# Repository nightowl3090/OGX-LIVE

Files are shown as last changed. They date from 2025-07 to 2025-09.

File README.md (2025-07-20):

# OGX-LIVE
OGX-Mini Boards OGX-LIVE Shell 

Fully Integrated OGX-Mini and Xbox Live Communicator
The all-in-one solution for using modern controllers on Insignia

Combining the advanced controller emulation support of WiredOpposite's OGX-Mini with Ryzee119's HAWK communicator, you can now play online with the comfort and precision of modern controllers while berating your Warthog driver for going in the wrong direction.

Configs Recommended Configurations 

Advanced Mixer Configurations 

[**Visit the web app here**](https://wiredopposite.github.io/OGX-Mini-WebApp/) to change your mappings and deadzone settings. To pair the OGX-Mini with the web app via USB, plug your controller in, then connect it to your PC, hold **Start + Left Bumper + Right Bumper** to enter web app mode. Click "Connect via USB" in the web app and select the OGX-Mini. You can also pair via Bluetooth, no extra steps are needed in that case. 

## Supported platforms
- Original Xbox
- Playstation 3
- Nintendo Switch (docked)
- XInput (use [**UsbdSecPatch**](https://github.com/InvoxiPlayGames/UsbdSecPatch) for Xbox 360, or select the patch in J-Runner while flashing your NAND)
- Playstation Classic
- DInput

## Changing platforms
By default the OGX-Mini will emulate an OG Xbox controller, you must hold a button combo for 3 seconds to change which platform you want to play on. Your chosen mode will persist after powering off the device. 

Start = Plus (Switch) = Options (Dualsense/DS4)

- XInput
    - Start + Dpad Up 
- Original Xbox
    - Start + Dpad Right
- Original Xbox Steel Battalion
    - Start + Dpad Right + Right Bumper
- Original Xbox DVD Remote
    - Start + Dpad Right + Left Bumper
- Switch
    - Start + Dpad Down
- PlayStation 3
    - Start + Dpad Left
- PlayStation Classic
    - Start + A (Cross for PlayStation and B for Switch gamepads)
- Web Application Mode
    - Start + Left Bumper + Right Bumper

After a new mode is stored, the RP2040 will reset itself so you don't need to unplug it.

## Supported devices
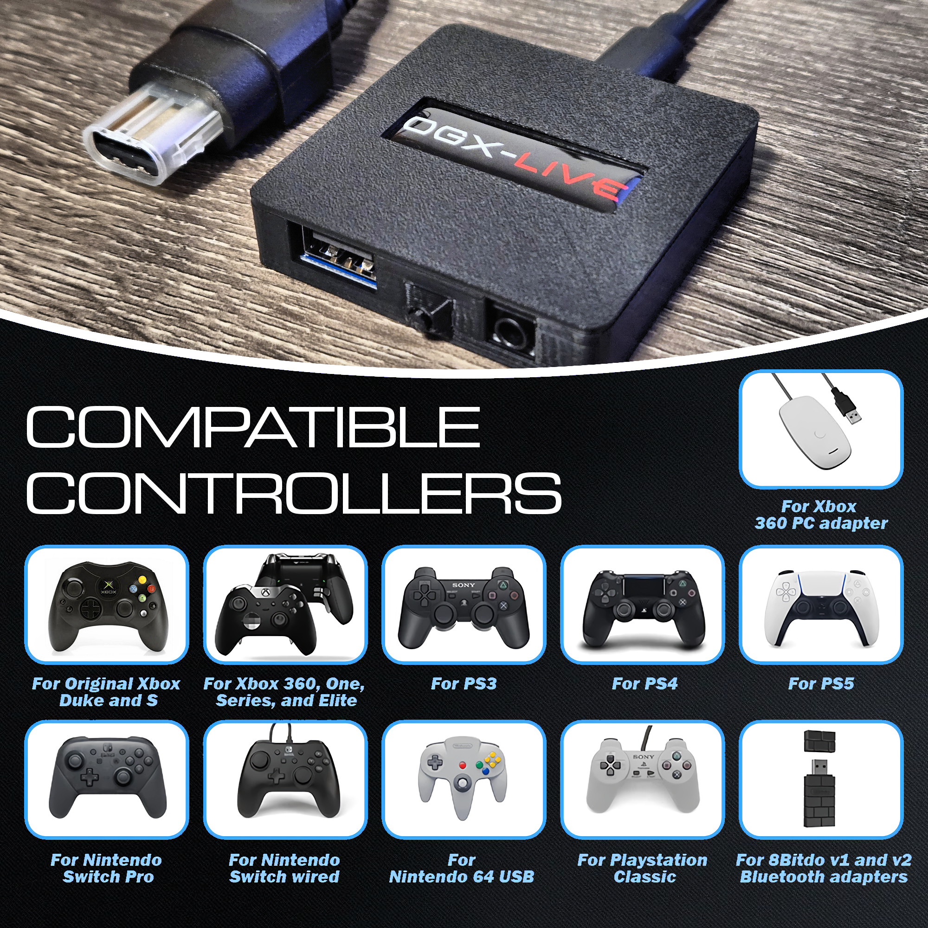
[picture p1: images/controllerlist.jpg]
Controller List
 
### Wired controllers
- Original Xbox Duke and S
- Xbox 360, One, Series, and Elite
- Dualshock 3 (PS3)
- Dualshock 4 (PS4)
- Dualsense (PS5)
- Nintendo Switch Pro
- Nintendo Switch wired
- Nintendo 64 Generic USB
- Playstation Classic
- Generic DInput
- Generic HID (mappings may need to be editted in the web app)

Note: There are some third party controllers that can change their VID/PID, these might not work correctly.

### Wireless adapters
- Xbox 360 PC adapter (Microsoft or clones)
- 8Bitdo v1 and v2 Bluetooth adapters (set to XInput mode)
- Most wireless adapters that present themselves as Switch/XInput/PlayStation controllers should work

### Wireless Bluetooth controllers (Pico W & ESP32)
**Note:** Bluetooth functionality is in early testing, some may have quirks.
- Xbox Series, One, and Elite 2
- Dualshock 3
- Dualshock 4
- Dualsense
- Switch Pro
- Steam
- Stadia
- And more

Please visit [**this page**](https://bluepad32.readthedocs.io/en/latest/supported_gamepads/) for a more comprehensive list of supported controllers and Bluetooth pairing instructions.

## Features new to v1.0.0
- Bluetooth functionality for the Pico W, Pico 2 W, and Pico+ESP32.
- Web application (connectable via USB or Bluetooth) for configuring deadzones and buttons mappings, supports up to 8 saved profiles.
- Pi Pico 2 and Pico 2 W (RP2350) support.
- Reduced latency by about 3-4 ms, graphs showing comparisons are coming.
- 4 channel functionality, connect 4 Picos and use one Xbox 360 wireless adapter to control all 4.
- Delayed USB mount until a controller is plugged in, useful for internal installation (non-Bluetooth boards only). 
- Generic HID controller support.
- Dualshock 3 emulation (minus gyros), rumble now works.
- Steel Battalion controller emulation with a wireless Xbox 360 chatpad.
- Xbox DVD dongle emulation. You must provide or dump your own dongle firmware, see the Tools directory.
- Analog button support on OG Xbox and PS3.
- RGB LED support for RP2040-Zero and Adafruit Feather boards.

## Planned additions
- More accurate report parser for unknown HID controllers
- Hardware design for internal OG Xbox install
- Hardware design for 4 channel RP2040-Zero adapter
- Wired Xbox 360 chatpad support
- Wired Xbox One chatpad support
- Switch (as input) rumble support
- Generic bluetooth dongle support
- Button macros
- Rumble settings (intensity, enabled/disable, etc.)

## Communicator Use

Recommended configuration: 12 foot 3.5mm TTRS cable and 12 foot USB-A cable
Alternatively you could use a USB-C extension and then shorter cable runs for the headset and controller.
8-BitDo or equivalent wireless adapter is necessary for wireless function. 

The OGX-LIVE provides feature parity with the original communicator with the following differences:
- Dual independent processors for gamepad and audio processing to eliminate latency
- Support for a wide array of modern controllers and input devices. Full list available on the OGX-LIVE Github repository
- A 3.5mm TRRS jack is used to support more generic headsets. (Stereo headsets will output as mono.)
- The volume wheel is replaced with a button. Volume is indicated by LED brightness.
- The Xbox chat feature only outputs voice audio, so a single ear chat headset is recommended.

Tip: When searching online for compatible headsets use the term: "mono chat headset 3.5" to get the best results for single ear chat headsets

Usage:
**Press the button to increment the volume. Once maximum volume is reached, it will cycle back to zero.
**Hold the button for 1 second to mute and disable the microphone input (LED will flash at 1Hz).
**Hold the button 2 seconds to enter microphone gain adjustment mode (LED will flash at 4Hz).
**Volume and microphone gain adjustments will be saved internally. You can reset these to default by holding the button down for 8 seconds.

FAQ:
Why can't I hear the in-game audio? 
- The original Xbox's headset was designed to playback chat audio only, however, with the use of an external mixer you could mix the audio output from the Xbox with the chat audio from the Hawk for a full headphone gaming experience. 
What is the pinout of the headphone jack?
- OGX-LIVE's headphone jack is wired as per CTIA standard TRRS. There is another less common standard called OMTP. This will not work but adapters are available.
Microphone is really quiet?
- You can increase the microphone gain above default. Hold the Hawk button down for more than 2 seconds to enter gain adjustment mode. The LED will blink 4 times per second to show it is in the right mode then press the button to increase the gain. Hold for 1 second to exit. If this is still too quiet, you can modify the MAX_MICROPHONE_GAIN variable and recompile the code to bump it up even higher.
Speaker is really quiet?
- Adjust the volume by pressing the button until the LED is at its maximum brightness. Unfortunately, it is already compiled to the maximum allowable by OGX-LIVE. If it is still too quiet, your headset's impedance may be too low.

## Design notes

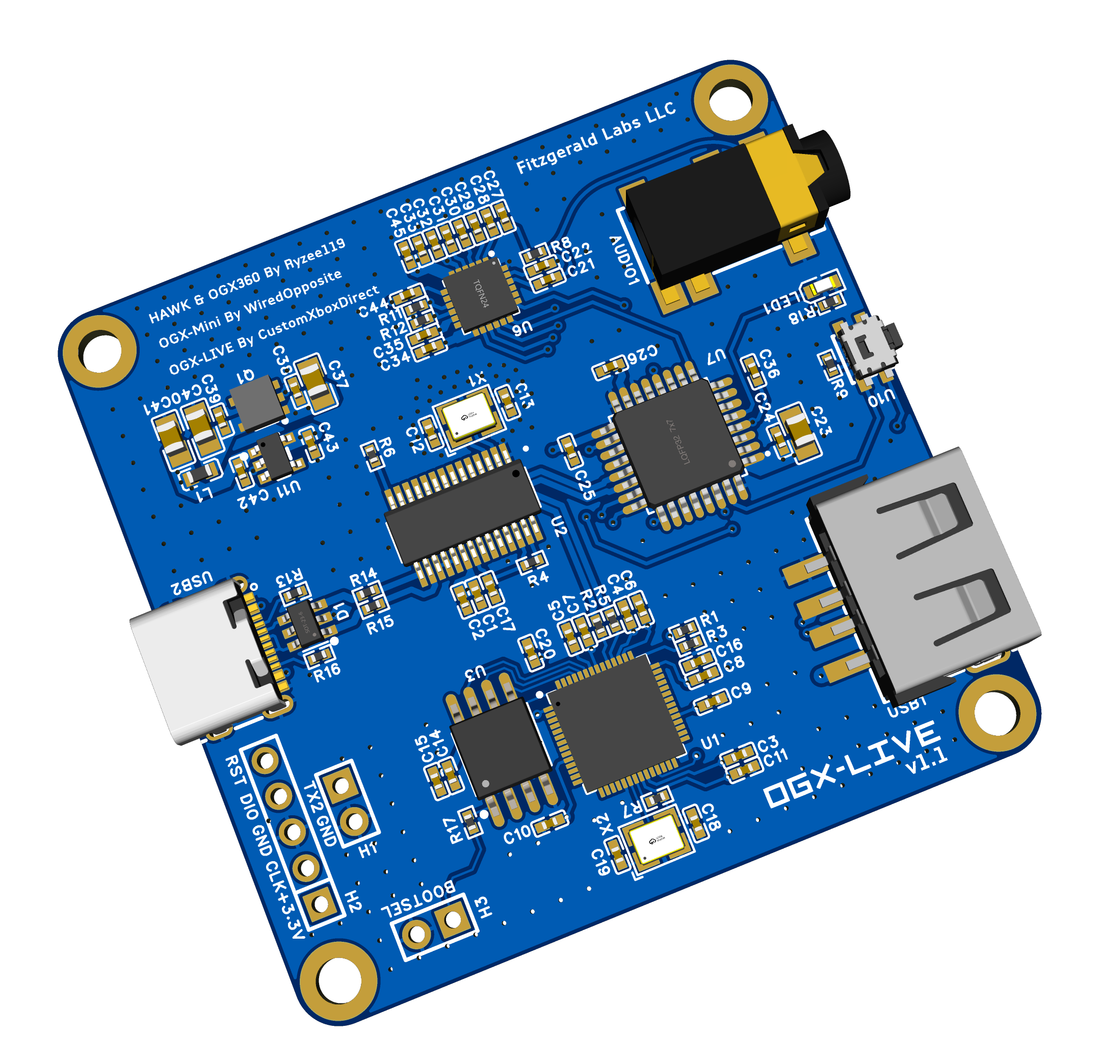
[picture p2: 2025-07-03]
images/3D_PCB1_2025-07-02.png

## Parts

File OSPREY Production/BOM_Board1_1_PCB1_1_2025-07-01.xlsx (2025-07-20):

No. | Quantity | Comment | Designator | Footprint | Value | Manufacturer Part | Manufacturer | Supplier Part | Supplier
1 | 1 | PJ-3420-A-SMT | AUDIO1 | AUDIO-SMD_PJ-3420-A-SMT_C319102 |  | PJ-3420-A-SMT | XKB Connectivity(中国星坤) | C319102 | LCSC
2 | 10 | 100nF | C1,C24,C25,C26,C33,C36,C38,C39,C42,C43 | C0402 | 100nF | CL05B104KO5NNNC | SAMSUNG(三星) | C1525 | LCSC
3 | 2 | 10uF | C2,C17 | C0402 | 10uF | CL05A106MQ5NUNC | SAMSUNG(三星) | C15525 | LCSC
4 | 2 | 15pF | C12,C13 | C0402 | 15pF | 0402CG150F500NT | FH(风华) | C285151 | LCSC
5 | 10 | 1uF | C21,C22,C27,C28,C29,C30,C31,C32,C34,C35 | C0402 |  | CC0402KRX5R5BB105 | YAGEO(国巨) | C106253 | LCSC
6 | 4 | 10uF | C23,C37,C40,C41 | C0805 |  | 0805X106M250NT | FH(风华) | C669099 | LCSC
7 | 2 | 10uF | C44,C45 | C0402 | 10uF | HGC0402R5106M100NTEJ | Chinocera(华瓷) | C7472949 | LCSC
8 | 1 | USBLC6-2SC6 | D1 | SOT-23-6_L2.9-W1.6-P0.95-LS2.8-BL |  | USBLC6-2SC6 | TECH PUBLIC(台舟) | C2827654 | LCSC
9 | 1 | MPZ1608S101ATAH0 | L1 | L0603 |  | MPZ1608S101ATAH0 | TDK | C107332 | LCSC
10 | 1 | XL-1608UGC-04 | LED1 | LED0603-RD_GREEN |  | XL-1608UGC-04 | XINGLIGHT(成兴光) | C965804 | LCSC
11 | 1 | XC6220B331MR-G | Q1 | SOT-25_L3.0-W1.6-P0.95-LS2.8-TL |  | XC6220B331MR-G | TOREX(特瑞仕) | C86534 | LCSC
12 | 1 | 2.7kΩ | R6 | R0402 | 2.7kΩ | 0402WGF2701TCE | UNI-ROYAL(厚声) | C25885 | LCSC
13 | 4 | 1.5kΩ | R8,R9,R11,R12 | R0402 | 1.5kΩ | RC0402FR-071K5L | YAGEO(国巨) | C114759 | LCSC
14 | 2 | 5.1kΩ | R13,R16 | R0402 | 5.1kΩ | 0402WGF5101TCE | UNI-ROYAL(厚声) | C25905 | LCSC
15 | 2 | 0Ω | R14,R15 | R0402 | 0Ω | 0402WGF0000TCE | UNI-ROYAL(厚声) | C17168 | LCSC
16 | 1 | 150Ω | R18 | R0402 | 150Ω | RC0402FR-07150RL | YAGEO(国巨) | C138054 | LCSC
17 | 1 | FE1.1S-BSOP28BCN | U2 | SSOP-28_L9.9-W3.9-P0.64-LS6.0-BL-1 |  | FE1.1S-BSOP28BCN | TERMINUS | C9359 | LCSC
18 | 1 | MAX9860ETG+T | U6 | TQFN-24_L4.0-W4.0-P0.50-BL-EP |  | MAX9860ETG+T | ADI(亚德诺)/MAXIM(美信) | C516787 | LCSC
19 | 1 | STM32G431K6T6 | U7 | LQFP-32_L7.0-W7.0-P0.80-LS9.0-BL |  | STM32G431K6T6 | ST(意法半导体) | C730097 | LCSC
20 | 1 | TSC4A 160gf-WZ 016 | U10 | KEY-SMD_TSC4A |  | TSC4A 160gf-WZ 016 | SHOU HAN(首韩) | C2906284 | LCSC
21 | 1 | XC6220B181MR | U11 | SOT-23-5_L2.9-W1.6-P0.95-LS2.8-BR |  | XC6220B181MR | TDSEMIC(拓电半导体) | C22466447 | LCSC
22 | 1 | 10.0 QHHTZB6.3 | USB1 | USB-A-TH_10.0QHHTZB6.3 |  | 10.0 QHHTZB6.3 | SHOU HAN(首韩) | C668591 | LCSC
23 | 1 | USB-310-B-SU | USB2 | USB-C-SMD_20P-P0.50-L7.4-W8.9 |  | USB-310-B-SU | HOOYA(皓宇电子) | C309347 | LCSC
24 | 1 | 12MHz | X1 | OSC-SMD_4P-L3.2-W2.5-BL | 12MHz | X322512MSB4SI | YXC(扬兴晶振) | C9002 | LCSC

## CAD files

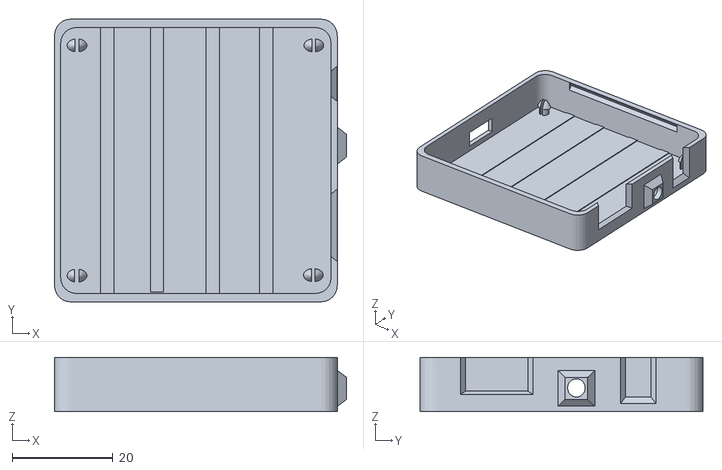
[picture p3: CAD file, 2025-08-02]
OGX-LIVE 3D Print Shell Files/OGX-LIVE Shell Bottom.stl
57.8 x 56.0 x 10.7

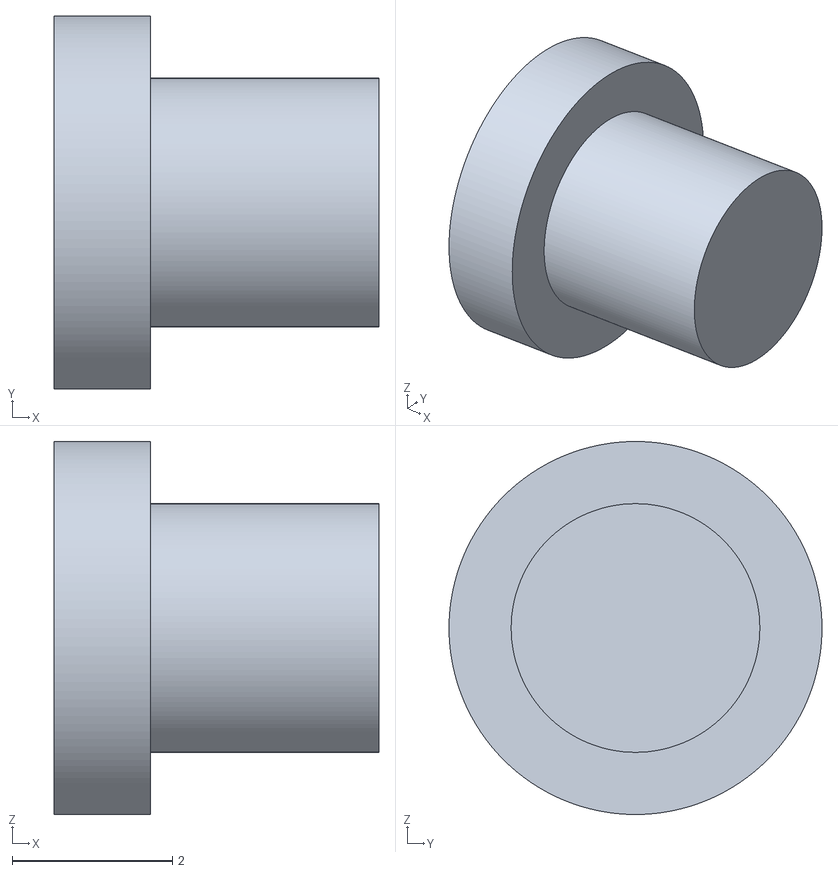
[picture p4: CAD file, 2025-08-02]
OGX-LIVE 3D Print Shell Files/OGX-LIVE Shell Button.stl
4.05 x 4.65 x 4.65

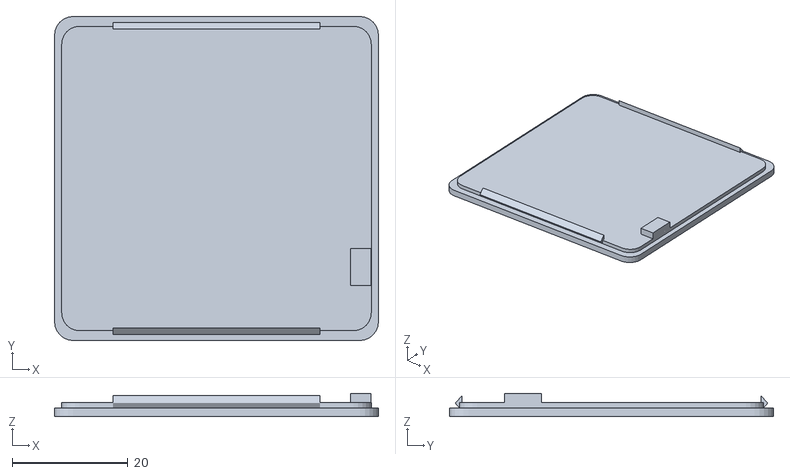
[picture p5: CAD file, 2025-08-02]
OGX-LIVE 3D Print Shell Files/OGX-LIVE Shell Top.stl
56.0 x 56.0 x 3.98

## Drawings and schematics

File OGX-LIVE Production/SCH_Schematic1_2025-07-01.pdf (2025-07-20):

## Raspberry Pi

# QSPI_SD3 51 DVDD ⁵⁰

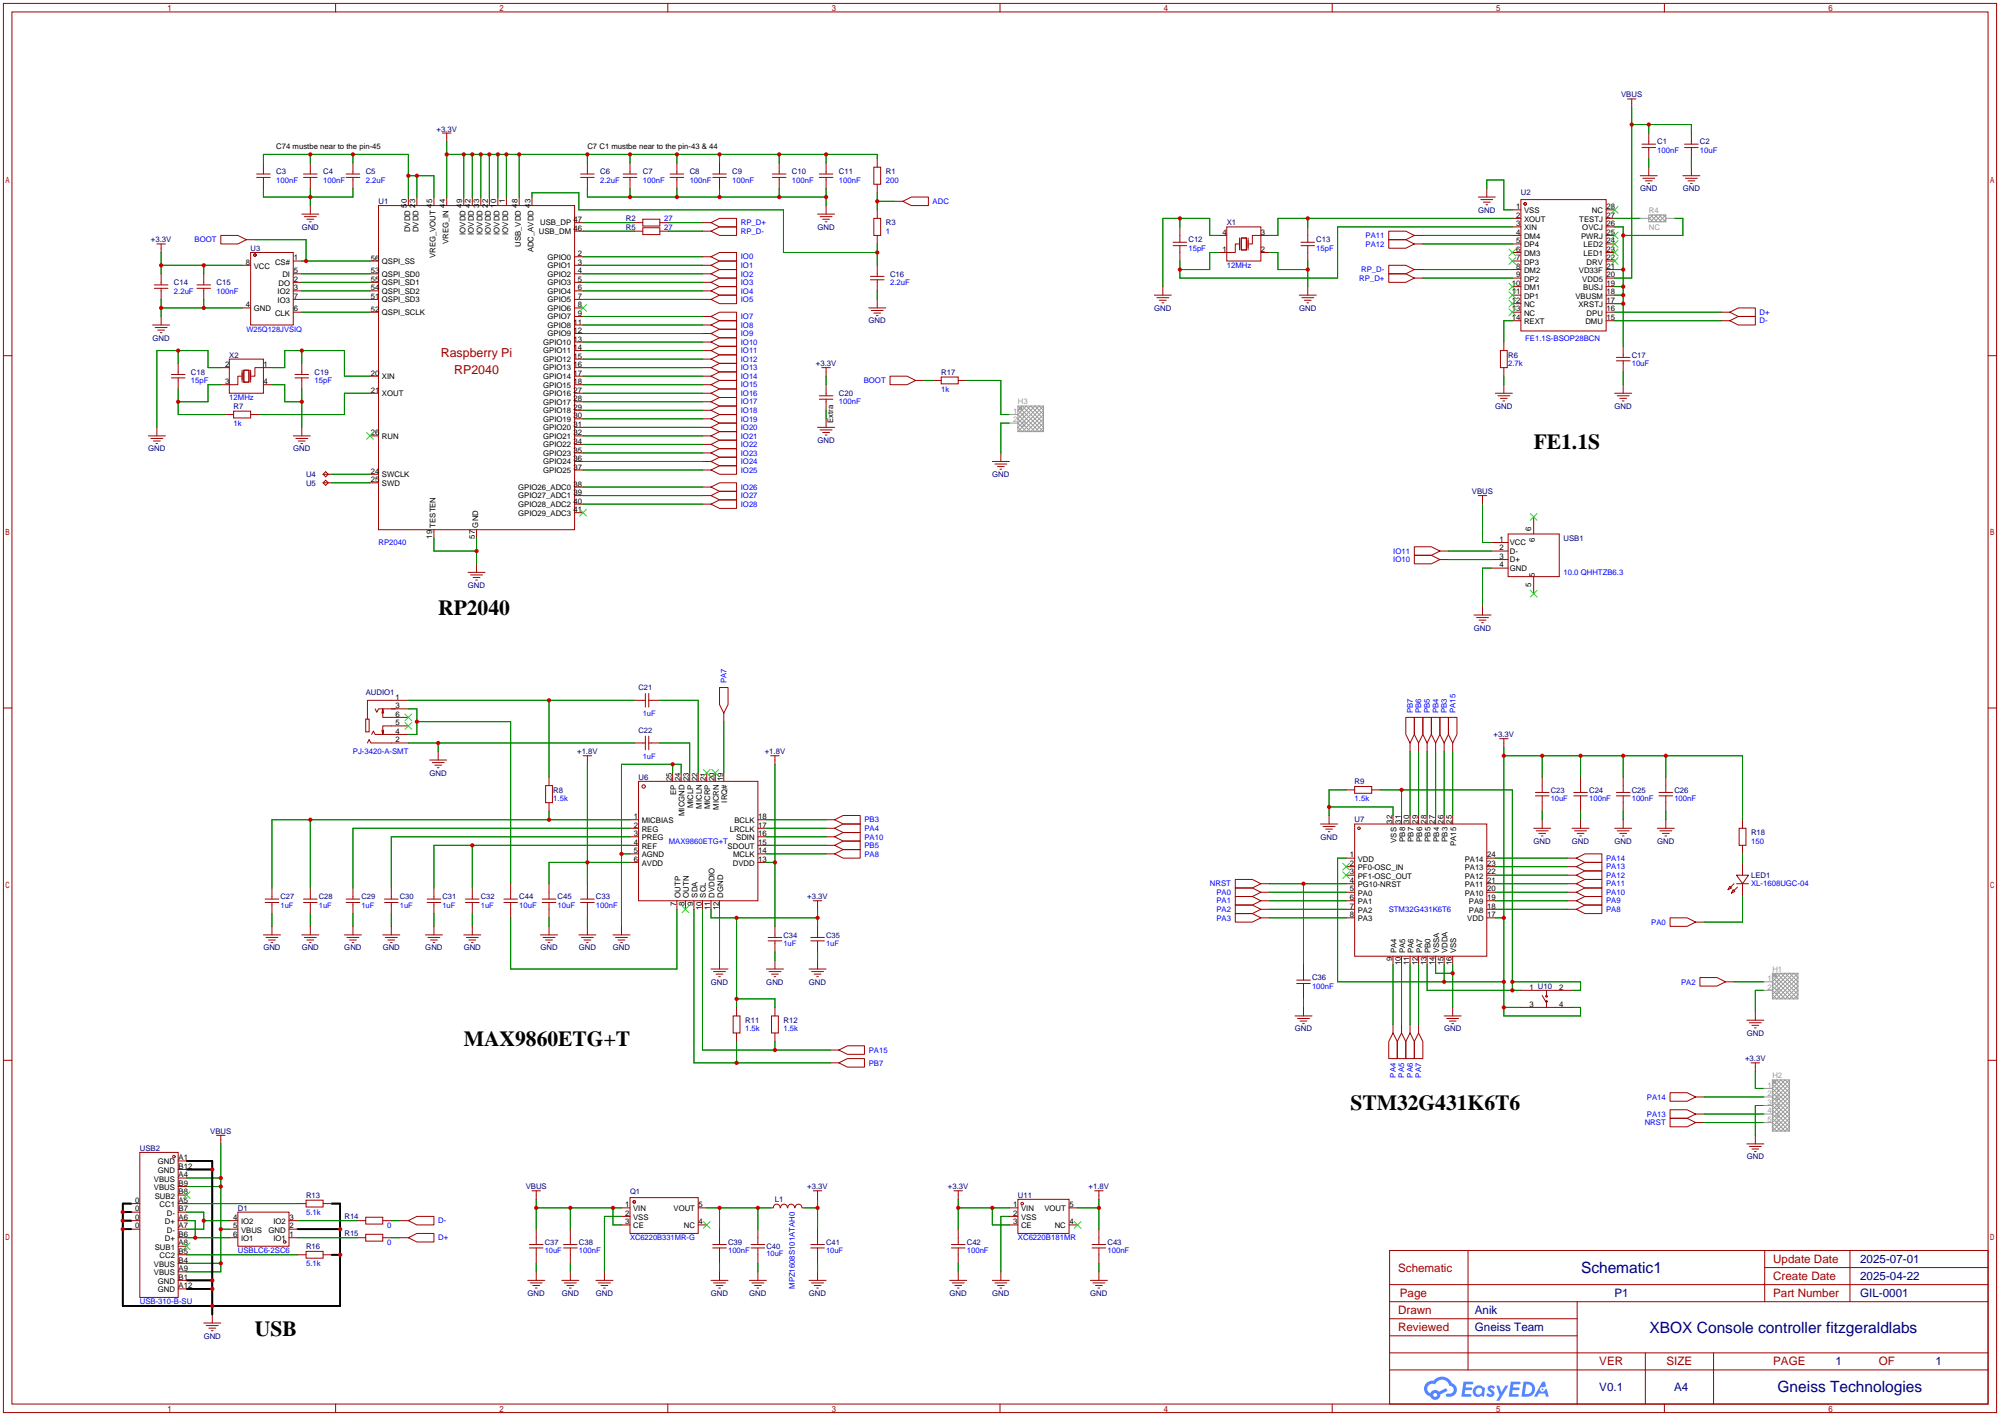
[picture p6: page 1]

IRQ# 19 MICRN 20 MICRP 21 MICLN 22 MICLP 23 MICGND 24 EP

DVDD 13 MCLK 14 SDOUT 15 SDIN 16 LRCLK 17 BCLK 18

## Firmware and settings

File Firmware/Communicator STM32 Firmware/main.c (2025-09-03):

// SPDX-License-Identifier: MIT
// SPDX-FileCopyrightText: 2024 Ryan Wendland

// i2S Audio codec to USB bridge.
// USB is coded to simulate an Xbox Live Communicator for the Original Xbox
// I2S is generated with STMs SAI interface as a slave device. The audio codex is a MAX9860 and is the master device.
// The STM provides a master clock to the MAX9860 using MCO and the MAX9860 provides the bit clock and frame sync back
// to the STM. The master clock is provided to the MAX9860 by STM's HSI48 which is automatically adjusted to match the
// USB clock using the clock recovery system. This eliminates the need for a crystal or other clock source and prevents
// drift between the USB clock and onboard clocks. All the I2s audio processing is circular DMA/interrupt driven and is
// pushed into a FIFO buffer for microphone data, and read from a FIFO buffer for speaker data. The USB interface reads
// from the FIFO for microphone data and writes to the FIFO for speaker data. This is all interrupt driven.

#include "main.h"
#include "eeprom_emulation/ee.h"
#include "max9860/max9860.h"
#include "usbd/usb_device.h"
#include "fifo.h"

#define RAM_FUNC __attribute__((section(".RamFunc")))
#define MCO_FREQ 12000000UL  // 48Mhz / 4 See SystemClock_Config

void SystemClock_Config(void);
static void MX_GPIO_Init(void);
static void MX_DMA_Init(void);
static void MX_I2C1_Init(void);
static void MX_SAI1_Init(void);
static void MX_USART2_UART_Init(void);
static void MX_TIM2_Init(void);
static void set_led_brightness(uint8_t percent);
static void start_new_audio_stream(uint32_t sample_rate);

// Peripheral handles
I2C_HandleTypeDef hi2c1;
SAI_HandleTypeDef hsai_BlockA1; // Speaker
SAI_HandleTypeDef hsai_BlockB1; // Microphone
DMA_HandleTypeDef hdma_sai1_a;
DMA_HandleTypeDef hdma_sai1_b;
TIM_HandleTypeDef htim2;
UART_HandleTypeDef huart2;

// Codec
static max9860_device_t max9860;
static uint32_t pending_sample_rate_change = 0;
static uint8_t pending_agc_change = 0;
static uint8_t microphone_muted = 0;

// Non volatile storage
#define HAWK_MAGIC (0x4841574B)
typedef struct {
    uint32_t magic;
    int8_t volume;
    uint8_t mic_gain;
    uint8_t reserved[2];
} hawk_storage_t;
hawk_storage_t ee;
uint32_t ee_dirty = 0;

// Data fifos for linking USB and SAI I2S
#define FIFO_BUFF_SZ (48 * 8)
static fifo_t fifo_speaker;
static fifo_t fifo_mic;
static uint8_t fifo_speaker_buffer[FIFO_BUFF_SZ];
static uint8_t fifo_mic_buffer[FIFO_BUFF_SZ];

// UART FIFO
static uint8_t uart_fifo[256];
static uint32_t uart_fifo_head = 0, uart_fifo_tail = 0;
void io_puts(const char *s, void *ctx) {
    while (*s) {
        uart_fifo[uart_fifo_tail] = *s++;
        uart_fifo_tail = (uart_fifo_tail + 1) % sizeof(uart_fifo);
    }
}

// Circular DMA buffers for SAI TX and RX
#define SAI_DMA_BUFFER_BYTES (FIFO_BUFF_SZ)
static uint8_t tx_dma_buffer[SAI_DMA_BUFFER_BYTES] __attribute__((aligned(4)));
static uint8_t rx_dma_buffer[SAI_DMA_BUFFER_BYTES] __attribute__((aligned(4)));

// LED
static uint32_t led_rate = 0;
static uint8_t led_brightness = 0;

void (*SysMemBootJump)(void);

int main(void) {
    HAL_Init();
    SystemClock_Config();

    // Initialize all configured peripherals
    MX_GPIO_Init();
    MX_DMA_Init();
    MX_USART2_UART_Init();
    MX_I2C1_Init();
    MX_SAI1_Init();
    MX_TIM2_Init();
    MX_USB_Device_Init();

    io_puts("HAWK!\n", NULL);

    // Emulated EEPROM
    EE_Init(&ee, sizeof(ee));
    EE_Read();
    if (ee.magic != HAWK_MAGIC) {
        io_puts("EEPROM RESET\n", NULL);
        memset(&ee, 0, sizeof(ee));
        ee.magic = HAWK_MAGIC;
        ee.volume = DEFAULT_SPEAKER_GAIN;
        ee.mic_gain = DEFAULT_MICROPHONE_GAIN;
        EE_Write(true);
    }

    if (max9860_init(&max9860, &hi2c1, MCO_FREQ) == false) {
        io_puts("MAX9860 INIT FAILED\n", NULL);
        while (1) {
            set_led_brightness(100);
            HAL_Delay(100);
            set_led_brightness(0);
            HAL_Delay(100);
        }
    }

    // Setup audio codec
    max9860_set_volume(&max9860, 20);
    max9860_mic_agc_enable(&max9860);
    max9860_start(&max9860);
    led_brightness = (((ee.volume - MIN_SPEAKER_GAIN) * 100) / (MAX_SPEAKER_GAIN - MIN_SPEAKER_GAIN));
    led_rate = 0;

    // Prepare FIFOs
    fifo_init(&fifo_speaker, fifo_speaker_buffer, sizeof(fifo_speaker_buffer));
    fifo_init(&fifo_mic, fifo_mic_buffer, sizeof(fifo_mic_buffer));

    // Start the I2s Interface DMA circular buffer.
    start_new_audio_stream(DEFAULT_SAMPLE_RATE);

    while (1) {
        uint32_t current_tick = HAL_GetTick();

        // Process and clear max9860 IRQs
        if (max9860.has_irq) {
            max9860.has_irq = false;
            // Read and clear the status
            if (max9860_get_irq_status(&max9860)) {
                io_puts("IRQ: ", NULL);
                io_puts((max9860.INTRSTATUS & MAX9860_CLD) ? "CLD " : "", NULL);
                io_puts((max9860.INTRSTATUS & MAX9860_SLD) ? "SLD " : "", NULL);
                io_puts((max9860.INTRSTATUS & MAX9860_ULK) ? "ULK " : "", NULL);
                io_puts("\n", NULL);
            }
        }

        // Handle a sample rate change
        if (pending_sample_rate_change) {
            io_puts("SR: ", NULL);
            io_puts((pending_sample_rate_change == 8000)    ? "8k"
                    : (pending_sample_rate_change == 11025) ? "11k"
                    : (pending_sample_rate_change == 16000) ? "16k"
                    : (pending_sample_rate_change == 22050) ? "22k"
                    : (pending_sample_rate_change == 24000) ? "24k"
                                                            : "???",
                    NULL);
            io_puts("\n", NULL);
            start_new_audio_stream(pending_sample_rate_change);
            pending_sample_rate_change = 0;
        }

        // Handle auto gain control toggle
        if (pending_agc_change & 0x80) {
            uint8_t agc = pending_agc_change & 0x7F;
            pending_agc_change = 0;
            io_puts("AGC: ", NULL);
            io_puts(agc ? "ON\n" : "OFF\n", NULL);
            if (agc) {
                max9860_mic_agc_enable(&max9860);
            } else {
                max9860_mic_agc_disable(&max9860, DEFAULT_MICROPHONE_GAIN);
                max9860_set_mic_gain(&max9860, ee.mic_gain);
            }
            pending_agc_change = 0;
        }

        // Flush UART fifo
        if (uart_fifo_head != uart_fifo_tail) {
            uint32_t len = (uart_fifo_head < uart_fifo_tail) ? (uart_fifo_tail - uart_fifo_head)
                                                             : (sizeof(uart_fifo) - uart_fifo_head);
            HAL_UART_Transmit(&huart2, &uart_fifo[uart_fifo_head], len, 0xFFFF);
            uart_fifo_head = (uart_fifo_head + len) % sizeof(uart_fifo);
        }

        // Prevent thrashing emulated eeprom. Only write if dirty and some period has passed
        if (ee_dirty && (HAL_GetTick() - ee_dirty) > 10000) {
            EE_Write(true);
            ee_dirty = 0;
            io_puts("EEPROM WRITTEN\n", NULL);
        }

        // Handle flashing of the LED
        static uint32_t led_tick = 0;
        static uint32_t tgl = 0;
        uint32_t led_held = current_tick - led_tick;
        if (led_rate) {
            if (led_held > led_rate) {
                led_tick = current_tick;
                set_led_brightness((tgl ^= 1) ? led_brightness : 0);
            }
        } else {
            set_led_brightness(led_brightness);
        }

        // The button has 4 modes. Normal, Mute, Mic Gain, and EEPROM Reset
        // Normal mode adjusts the volume. The LED brightness is set to the volume level.
        // Mute does not transfer any microphone information. This is indicated a slow flash of the LED.
        // Mic Gain mode makes the button adjust the microphone gain. This is indicated by a medium flash of the LED.
        // EEPROM Reset mode resets the EEPROM to defaults this is indicated by a fast flash of the LED.
        typedef enum { NORMAL_MODE, MUTE_MODE, MIC_GAIN_MODE, EEPROM_RESET_MODE } button_mode_t;
        static button_mode_t button_mode = NORMAL_MODE;
        static uint8_t last_button_state = 0;
        static uint32_t button_pressed_tick = 0;

        uint8_t button_state = HAL_GPIO_ReadPin(BUTTON_GPIO_Port, BUTTON_Pin);
        if (button_state && button_state != last_button_state) {
            button_pressed_tick = current_tick;
        }

        if (!button_state && button_state != last_button_state) {
            if (current_tick - button_pressed_tick > 8000) {
                io_puts("EEPROM RESET\n", NULL);
                button_mode = EEPROM_RESET_MODE;
                led_rate = 100;
                led_brightness = 100;
                memset(&ee, 0, sizeof(ee));
                ee.magic = HAWK_MAGIC;
                ee.volume = DEFAULT_SPEAKER_GAIN;
                ee.mic_gain = DEFAULT_MICROPHONE_GAIN;
                EE_Write(true);

            } else if (current_tick - button_pressed_tick > 2000) {
                io_puts("MIC GAIN\n", NULL);
                button_mode = (button_mode == MIC_GAIN_MODE) ? NORMAL_MODE : MIC_GAIN_MODE;
                microphone_muted = 0;
                led_rate = 250;
                led_brightness =
                    (((ee.mic_gain - MIN_MICROPHONE_GAIN) * 100) / (MAX_MICROPHONE_GAIN - MIN_MICROPHONE_GAIN));

            } else if (current_tick - button_pressed_tick > 500) {
                if (button_mode != MIC_GAIN_MODE) {
                    io_puts("MUTE\n", NULL);
                    button_mode = MUTE_MODE;
                    led_rate = 1000;
                    led_brightness = 50;
                    microphone_muted = 1;
                } else {
                    button_mode = NORMAL_MODE;
                    led_rate = 0;
                    led_brightness = (((ee.volume - MIN_SPEAKER_GAIN) * 100) / (MAX_SPEAKER_GAIN - MIN_SPEAKER_GAIN));
                }

            } else if (current_tick - button_pressed_tick > 50) {
                if (button_mode == NORMAL_MODE) {
                    ee.volume += SPEAKER_INCREMEMENT;
                    // When it reaches max, one more press is no change, 2nd press resets to zero
                    if (ee.volume > (MAX_SPEAKER_GAIN + SPEAKER_INCREMEMENT)) {
                        ee.volume = MIN_SPEAKER_GAIN;
                    }
                    max9860_set_volume(&max9860, ee.volume);
                    led_brightness = (((ee.volume - MIN_SPEAKER_GAIN) * 100) / (MAX_SPEAKER_GAIN - MIN_SPEAKER_GAIN));
                    ee_dirty = HAL_GetTick();

                } else if (button_mode == MIC_GAIN_MODE) {
                    ee.mic_gain += MICROPHONE_INCREMEMENT;
                    // When it reaches max, one more press is no change, 2nd press resets to zero
                    if (ee.mic_gain > (MAX_MICROPHONE_GAIN + MICROPHONE_INCREMEMENT)) {
                        ee.mic_gain = MIN_MICROPHONE_GAIN;
                    }
                    max9860_set_mic_gain(&max9860, ee.mic_gain);
                    led_brightness =
                        (((ee.mic_gain - MIN_MICROPHONE_GAIN) * 100) / (MAX_MICROPHONE_GAIN - MIN_MICROPHONE_GAIN));
                    ee_dirty = HAL_GetTick();

                } else {
                    microphone_muted = 0;
                    led_rate = 0;
                    button_mode = NORMAL_MODE;
                }
            }
        }
        last_button_state = button_state;
    }
}

static inline void set_led_brightness(uint8_t percent) {
    __HAL_TIM_SET_COMPARE(&htim2, TIM_CHANNEL_1, percent);
}

void start_new_audio_stream(uint32_t sample_rate) {
    HAL_SAI_DMAStop(&hsai_BlockA1);
    HAL_SAI_DMAStop(&hsai_BlockB1);

    max9860_set_sample_rate(&max9860, sample_rate);

    memset(tx_dma_buffer, 0, SAI_DMA_BUFFER_BYTES);
    memset(rx_dma_buffer, 0, SAI_DMA_BUFFER_BYTES);

    HAL_SAI_Transmit_DMA(&hsai_BlockA1, tx_dma_buffer, SAI_DMA_BUFFER_BYTES / 2);
    HAL_SAI_Receive_DMA(&hsai_BlockB1, rx_dma_buffer, SAI_DMA_BUFFER_BYTES / 2);
}

// SAI uses a circular DMA. This has two call backs. One when half the buffer is complete and another when fully
// complete We use these callbacks to refill the buffer with data from the FIFO or push data to the FIFO
RAM_FUNC void HAL_SAI_TxHalfCpltCallback(SAI_HandleTypeDef *hsai) {
    fifo_read(&fifo_speaker, &tx_dma_buffer[0], SAI_DMA_BUFFER_BYTES / 2);
}

RAM_FUNC void HAL_SAI_TxCpltCallback(SAI_HandleTypeDef *hsai) {
    fifo_read(&fifo_speaker, &tx_dma_buffer[SAI_DMA_BUFFER_BYTES / 2], SAI_DMA_BUFFER_BYTES / 2);
}

RAM_FUNC void HAL_SAI_RxHalfCpltCallback(SAI_HandleTypeDef *hsai) {
    if (!microphone_muted)
        fifo_write(&fifo_mic, &rx_dma_buffer[0], SAI_DMA_BUFFER_BYTES / 2);
}

RAM_FUNC void HAL_SAI_RxCpltCallback(SAI_HandleTypeDef *hsai) {
    if (!microphone_muted)
        fifo_write(&fifo_mic, &rx_dma_buffer[SAI_DMA_BUFFER_BYTES / 2], SAI_DMA_BUFFER_BYTES / 2);
}

RAM_FUNC void USBD_XBLC_Data_Received(USBD_HandleTypeDef *pdev, uint8_t *data, uint16_t sz) {
    fifo_write(&fifo_speaker, data, sz);
}

RAM_FUNC void USBD_XBLC_Get_Data(USBD_HandleTypeDef *pdev, uint8_t *data, uint16_t sz) {
    fifo_read(&fifo_mic, data, sz);
}

RAM_FUNC void USBD_XBLC_Sample_Rate_Changed(USBD_HandleTypeDef *pdev, uint32_t sample_rate) {
    pending_sample_rate_change = sample_rate;
}

RAM_FUNC void USBD_XBLC_AGC_Changed(USBD_HandleTypeDef *pdev, uint8_t value) {
    pending_agc_change = 0x80 | value;
}

void HAL_GPIO_EXTI_Callback(uint16_t GPIO_Pin) {
    if (GPIO_Pin == MAX9860_IRQ_Pin) {
        max9860.has_irq = true;
    }
}

void SystemClock_Config(void) {
    RCC_OscInitTypeDef RCC_OscInitStruct = {0};
    RCC_ClkInitTypeDef RCC_ClkInitStruct = {0};
    RCC_CRSInitTypeDef pInit = {0};

    HAL_PWREx_ControlVoltageScaling(PWR_REGULATOR_VOLTAGE_SCALE1);

    // PLL setup quite low only at 16Mhz. All hardware driven so we dont need much and saves power
    RCC_OscInitStruct.OscillatorType = RCC_OSCILLATORTYPE_HSI | RCC_OSCILLATORTYPE_HSI48;
    RCC_OscInitStruct.HSIState = RCC_HSI_ON;
    RCC_OscInitStruct.HSICalibrationValue = RCC_HSICALIBRATION_DEFAULT;
    RCC_OscInitStruct.HSI48State = RCC_HSI48_ON;
    RCC_OscInitStruct.PLL.PLLState = RCC_PLL_ON;
    RCC_OscInitStruct.PLL.PLLSource = RCC_PLLSOURCE_HSI;
    RCC_OscInitStruct.PLL.PLLM = RCC_PLLM_DIV1;
    RCC_OscInitStruct.PLL.PLLN = 8;
    RCC_OscInitStruct.PLL.PLLP = RCC_PLLP_DIV2;
    RCC_OscInitStruct.PLL.PLLQ = RCC_PLLQ_DIV2;
    RCC_OscInitStruct.PLL.PLLR = RCC_PLLR_DIV8;
    if (HAL_RCC_OscConfig(&RCC_OscInitStruct) != HAL_OK) {
        Error_Handler();
    }

    RCC_ClkInitStruct.ClockType = RCC_CLOCKTYPE_HCLK | RCC_CLOCKTYPE_SYSCLK | RCC_CLOCKTYPE_PCLK1 | RCC_CLOCKTYPE_PCLK2;
    RCC_ClkInitStruct.SYSCLKSource = RCC_SYSCLKSOURCE_PLLCLK;
    RCC_ClkInitStruct.AHBCLKDivider = RCC_SYSCLK_DIV1;
    RCC_ClkInitStruct.APB1CLKDivider = RCC_HCLK_DIV1;
    RCC_ClkInitStruct.APB2CLKDivider = RCC_HCLK_DIV1;

    if (HAL_RCC_ClockConfig(&RCC_ClkInitStruct, FLASH_LATENCY_0) != HAL_OK) {
        Error_Handler();
    }

    HAL_RCC_MCOConfig(RCC_MCO1, RCC_MCO1SOURCE_HSI48, RCC_MCODIV_4);

    __HAL_RCC_CRS_CLK_ENABLE();
    pInit.Prescaler = RCC_CRS_SYNC_DIV1;
    pInit.Source = RCC_CRS_SYNC_SOURCE_USB;
    pInit.Polarity = RCC_CRS_SYNC_POLARITY_RISING;
    pInit.ReloadValue = __HAL_RCC_CRS_RELOADVALUE_CALCULATE(48000000, 1000);
    pInit.ErrorLimitValue = 34;
    pInit.HSI48CalibrationValue = 32;

    HAL_RCCEx_CRSConfig(&pInit);
}

static void MX_I2C1_Init(void) {
    hi2c1.Instance = I2C1;
    hi2c1.Init.Timing = 0x00303D5B;
    hi2c1.Init.OwnAddress1 = 0;
    hi2c1.Init.AddressingMode = I2C_ADDRESSINGMODE_7BIT;
    hi2c1.Init.DualAddressMode = I2C_DUALADDRESS_DISABLE;
    hi2c1.Init.OwnAddress2 = 0;
    hi2c1.Init.OwnAddress2Masks = I2C_OA2_NOMASK;
    hi2c1.Init.GeneralCallMode = I2C_GENERALCALL_DISABLE;
    hi2c1.Init.NoStretchMode = I2C_NOSTRETCH_DISABLE;

    HAL_I2C_Init(&hi2c1);
    HAL_I2CEx_ConfigAnalogFilter(&hi2c1, I2C_ANALOGFILTER_ENABLE);
    HAL_I2CEx_ConfigDigitalFilter(&hi2c1, 0);
}

static void MX_SAI1_Init(void) {
    hsai_BlockA1.Instance = SAI1_Block_A;
    hsai_BlockA1.Init.AudioMode = SAI_MODESLAVE_TX;
    hsai_BlockA1.Init.Synchro = SAI_SYNCHRONOUS;
    hsai_BlockA1.Init.OutputDrive = SAI_OUTPUTDRIVE_ENABLE;
    hsai_BlockA1.Init.FIFOThreshold = SAI_FIFOTHRESHOLD_HF;
    hsai_BlockA1.Init.SynchroExt = SAI_SYNCEXT_DISABLE;
    hsai_BlockA1.Init.MonoStereoMode = SAI_MONOMODE;
    hsai_BlockA1.Init.CompandingMode = SAI_NOCOMPANDING;
    hsai_BlockA1.Init.TriState = SAI_OUTPUT_NOTRELEASED;

    hsai_BlockB1.Instance = SAI1_Block_B;
    hsai_BlockB1.Init.AudioMode = SAI_MODESLAVE_RX;
    hsai_BlockB1.Init.Synchro = SAI_ASYNCHRONOUS;
    hsai_BlockB1.Init.OutputDrive = SAI_OUTPUTDRIVE_DISABLE;
    hsai_BlockB1.Init.FIFOThreshold = SAI_FIFOTHRESHOLD_HF;
    hsai_BlockB1.Init.SynchroExt = SAI_SYNCEXT_DISABLE;
    hsai_BlockB1.Init.MonoStereoMode = SAI_MONOMODE;
    hsai_BlockB1.Init.CompandingMode = SAI_NOCOMPANDING;
    hsai_BlockB1.Init.TriState = SAI_OUTPUT_NOTRELEASED;

    HAL_SAI_InitProtocol(&hsai_BlockA1, SAI_I2S_STANDARD, SAI_PROTOCOL_DATASIZE_16BIT, 2);
    HAL_SAI_InitProtocol(&hsai_BlockB1, SAI_I2S_STANDARD, SAI_PROTOCOL_DATASIZE_16BIT, 2);

    // Overwrite HAL Frame number with max9860 supported value
    hsai_BlockA1.Instance->FRCR &= ~SAI_xFRCR_FRL;
    hsai_BlockA1.Instance->FRCR |= 48U - 1U;

    hsai_BlockB1.Instance->FRCR &= ~SAI_xFRCR_FRL;
    hsai_BlockB1.Instance->FRCR |= 48U - 1U;
}

static void MX_TIM2_Init(void) {
    TIM_ClockConfigTypeDef sClockSourceConfig = {0};
    TIM_MasterConfigTypeDef sMasterConfig = {0};
    TIM_OC_InitTypeDef sConfigOC = {0};

    htim2.Instance = TIM2;
    htim2.Init.Prescaler = HAL_RCC_GetSysClockFreq() / 100000ULL;  // Count at 100khz
    htim2.Init.CounterMode = TIM_COUNTERMODE_UP;
    htim2.Init.Period = 100;  // Count up to 100 before reset. PWM freq is 100khz/100 = 1kHz
    htim2.Init.ClockDivision = TIM_CLOCKDIVISION_DIV1;
    htim2.Init.AutoReloadPreload = TIM_AUTORELOAD_PRELOAD_ENABLE;
    if (HAL_TIM_Base_Init(&htim2) != HAL_OK) {
        Error_Handler();
    }
    sClockSourceConfig.ClockSource = TIM_CLOCKSOURCE_INTERNAL;
    if (HAL_TIM_ConfigClockSource(&htim2, &sClockSourceConfig) != HAL_OK) {
        Error_Handler();
    }
    if (HAL_TIM_PWM_Init(&htim2) != HAL_OK) {
        Error_Handler();
    }
    sMasterConfig.MasterOutputTrigger = TIM_TRGO_RESET;
    sMasterConfig.MasterSlaveMode = TIM_MASTERSLAVEMODE_DISABLE;
    if (HAL_TIMEx_MasterConfigSynchronization(&htim2, &sMasterConfig) != HAL_OK) {
        Error_Handler();
    }
    sConfigOC.OCMode = TIM_OCMODE_PWM1;
    sConfigOC.Pulse = 0;
    sConfigOC.OCPolarity = TIM_OCPOLARITY_LOW;
    sConfigOC.OCFastMode = TIM_OCFAST_DISABLE;
    if (HAL_TIM_PWM_ConfigChannel(&htim2, &sConfigOC, TIM_CHANNEL_1) != HAL_OK) {
        Error_Handler();
    }
    HAL_TIM_MspPostInit(&htim2);
    HAL_TIM_PWM_Start(&htim2, TIM_CHANNEL_1);
}

static void MX_USART2_UART_Init(void) {
    huart2.Instance = USART2;
    huart2.Init.BaudRate = 115200;
    huart2.Init.WordLength = UART_WORDLENGTH_8B;
    huart2.Init.StopBits = UART_STOPBITS_1;
    huart2.Init.Parity = UART_PARITY_NONE;
    huart2.Init.Mode = UART_MODE_TX;
    huart2.Init.HwFlowCtl = UART_HWCONTROL_NONE;
    huart2.Init.OverSampling = UART_OVERSAMPLING_16;
    huart2.Init.OneBitSampling = UART_ONE_BIT_SAMPLE_DISABLE;
    huart2.Init.ClockPrescaler = UART_PRESCALER_DIV1;
    huart2.AdvancedInit.AdvFeatureInit = UART_ADVFEATURE_NO_INIT;

    HAL_UART_Init(&huart2);
    HAL_UARTEx_SetTxFifoThreshold(&huart2, UART_TXFIFO_THRESHOLD_1_8);
    HAL_UARTEx_SetRxFifoThreshold(&huart2, UART_RXFIFO_THRESHOLD_1_8);
    HAL_UARTEx_DisableFifoMode(&huart2);
}

static void MX_DMA_Init(void) {
    __HAL_RCC_DMAMUX1_CLK_ENABLE();
    __HAL_RCC_DMA1_CLK_ENABLE();

    HAL_NVIC_SetPriority(DMA1_Channel1_IRQn, 0, 0);
    HAL_NVIC_EnableIRQ(DMA1_Channel1_IRQn);
    HAL_NVIC_SetPriority(DMA1_Channel2_IRQn, 0, 0);
    HAL_NVIC_EnableIRQ(DMA1_Channel2_IRQn);
}

static void MX_GPIO_Init(void) {
    GPIO_InitTypeDef GPIO_InitStruct = {0};

    __HAL_RCC_GPIOA_CLK_ENABLE();
    __HAL_RCC_GPIOB_CLK_ENABLE();

    GPIO_InitStruct.Pin = MAX9860_IRQ_Pin;
    GPIO_InitStruct.Mode = GPIO_MODE_IT_RISING;
    GPIO_InitStruct.Pull = GPIO_PULLUP;
    HAL_GPIO_Init(MAX9860_IRQ_GPIO_Port, &GPIO_InitStruct);

    GPIO_InitStruct.Pin = BUTTON_Pin;
    GPIO_InitStruct.Mode = GPIO_MODE_INPUT;
    GPIO_InitStruct.Pull = GPIO_PULLDOWN;
    HAL_GPIO_Init(BUTTON_GPIO_Port, &GPIO_InitStruct);

    GPIO_InitStruct.Pin = MCO_MCLK_Pin;
    GPIO_InitStruct.Mode = GPIO_MODE_AF_PP;
    GPIO_InitStruct.Pull = GPIO_NOPULL;
    GPIO_InitStruct.Speed = GPIO_SPEED_FREQ_MEDIUM;
    GPIO_InitStruct.Alternate = GPIO_AF0_MCO;
    HAL_GPIO_Init(MCO_MCLK_GPIO_Port, &GPIO_InitStruct);

    HAL_NVIC_SetPriority(EXTI9_5_IRQn, 0, 0);
    HAL_NVIC_EnableIRQ(EXTI9_5_IRQn);
}

void Error_Handler(void) {
    while (1) {
        HAL_UART_Transmit(&huart2, (uint8_t *)"E\n", 2, 0xFFFF);
    }
    __disable_irq();
}
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

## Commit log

2025-07-20 Add files via upload
    OGX-LIVE Production Files
    [BOM_Board1_PCB1_2025-07-01.xlsx, PickAndPlace_PCB1_2025-07-01.xlsx]
2025-07-20 Add files via upload
    OSPREY Production Files
    [BOM_Board1_1_PCB1_1_2025-07-01.xlsx, PickAndPlace_PCB1_1_2025-07-01.xlsx]
2025-08-02 Latest build of HAWK Firmware
    Flash via STM32 Cube
2025-08-02 Current Shell Design
    Current Shell Design, featuring friction and snap fittings
    [OGX-LIVE Shell Bottom.stl, OGX-LIVE Shell Button.stl, OGX-LIVE Shell Top.stl]
2025-09-06 Open Source PCB Design Master File
    Open with EasyEDA Pro - matches release v1.1
